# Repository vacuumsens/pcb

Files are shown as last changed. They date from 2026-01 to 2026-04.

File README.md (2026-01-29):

# PCB Schematic Projects

KiCad PCB design projects for VacuumSens.

## Project Structure

```
SchematicProjects/
├── libs/                    # Centralized component libraries
│   ├── easyeda2kicad.kicad_sym
│   ├── easyeda2kicad.pretty/
│   └── easyeda2kicad.3dshapes/
├── charging-circuit/V1/     # Charging circuit project
├── RS232-converter/V1/      # RS232 converter project
└── ...
```

## Importing Components from EasyEDA/LCSC

There are two methods to import components:

---

### Method 1: Command Line (easyeda2kicad)

Best for batch imports or when you know the LCSC part number.

#### Prerequisites

Install the `easyeda2kicad` Python tool:

```bash
pip install easyeda2kicad
```

#### Import a Component

Use the alias (already configured in `.zshrc`):

```bash
easyeda2kicad-import <LCSC_ID>
```

**Example:**
```bash
easyeda2kicad-import C49018
```

This downloads the symbol, footprint, and 3D model to the centralized `libs/` folder.

#### Manual Import (without alias)

```bash
easyeda2kicad --full --overwrite --output /Users/andrewyanez/Documents/KiCad/7.0/symbols/SchematicProjects/libs --lcsc_id C49018
```

---

### Method 2: KiCad Plugin (EasyEDA/LCSC Plugin)

Best for browsing and importing directly within KiCad.

#### Installation

1. In KiCad, go to **Plugin and Content Manager**
2. Search for "EasyEDA" or "LCSC"
3. Install the plugin

#### Usage

1. Open your KiCad project
2. Go to **Tools → EasyEDA Library** (or similar menu item)
3. Search for a component by name or LCSC part number
4. Click **Import** - the plugin will create:
   - `LCSC/EasyEDA.kicad_sym` (symbols)
   - `LCSC/EasyEDA.pretty/` (footprints)
   - `LCSC/EasyEDA.3dshapes/` (3D models)

**Note:** The plugin saves files locally in your project folder under `LCSC/`. This is project-specific, not centralized.

---

### After Importing (Both Methods)

1. Open your KiCad project
2. The library should be available in the schematic/PCB editor
3. Add the new symbol/footprint to your design
4. Commit changes to git:
   ```bash
   git add -A && git commit -m "Add component CXXXXX"
   git push
   ```

---

### Which Method to Use?

| Method | Pros | Cons |
|---|---|---|
| **easyeda2kicad** (CLI) | Centralized in `libs/`, shared across projects | Requires terminal |
| **KiCad Plugin** | Visual browsing, integrated in KiCad | Project-local, can create duplicates |

**Recommendation:** Use the CLI for components you'll reuse. Use the plugin for quick project-specific imports.

## Library Configuration

Projects reference the centralized library using relative paths:

**sym-lib-table:**
```
(lib (name "easyeda2kicad")(type "KiCad")(uri "${KIPRJMOD}/../../libs/easyeda2kicad.kicad_sym"))
```

**fp-lib-table:**
```
(lib (name "easyeda2kicad")(type "KiCad")(uri "${KIPRJMOD}/../../libs/easyeda2kicad.pretty"))
```

## Finding LCSC Part Numbers

1. Go to [LCSC.com](https://www.lcsc.com) or [JLCPCB Parts](https://jlcpcb.com/parts)
2. Search for your component
3. The LCSC part number starts with "C" (e.g., C49018)

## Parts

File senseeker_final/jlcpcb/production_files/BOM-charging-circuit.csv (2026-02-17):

Comment | Designator | Footprint | LCSC | Quantity
0.1uF | C7 | C0402 | C1525 | 1
10k | R8,RPROG3 | R0805 | C17414 | 2
12V_Sensor | H1 | HDR-TH_2P-P2.54-V-M-1 | C124375 | 1
1k | RPROG1 | R1206 | C4410 | 1
22k | R3 | R0805 | C17560 | 1
22uF | C3,C4,C5,C8 | C1206 | C1859 | 4
22uF | L1,L2 | IND-SMD_L7.5-W7.5 | C19268629 | 2
3k | R4 | R0603 | C177274 | 1
4.7k | R10 | R0805 | C17673 | 1
4.7uF | C2,C6 | C0805 | C1779 | 2
470 | R11,R6,R7 | R0805 | C17710 | 3
5.1k | R1,R2 | R0603 | C23186 | 2
91k | R9 | R0805 | C17866 | 1
Battery Input | U5 | CONN-TH_S2B-PH-K-S-GW | C157932 | 1
Blue | LED1 | LED0805-R-RD | C2293 | 1
Green | LED3 | LED0805-R-RD | C2292 | 1
MCP73871 | U4 | QFN-20_L4.0-W4.0-P0.5-BL-EP | C511310 | 1
RaspberryPI | H2 | HDR-TH_2P-P2.54-V-M-1 | C124375 | 1
Red | LED2 | LED1206-R-RD_RED | C49018 | 1
Schottky | D4,D6 | SMA_L4.3-W2.6-LS5.2-RD | C8678 | 2
USB_C_Receptacle_PowerOnly_6P | J1 | TYPE-C-SMD_TYPE-C-6P | C283540 | 1
MT3608 | U2 | SOT-23-6_L2.9-W1.6-P0.95-LS2.8-BL |  | 1
MT3608 | U3 | SOT-23-6_L2.9-W1.6-P0.95-LS2.8-BL |  | 1
USB_A | J2 | USB-A-TH_AF-WJDG |  | 1

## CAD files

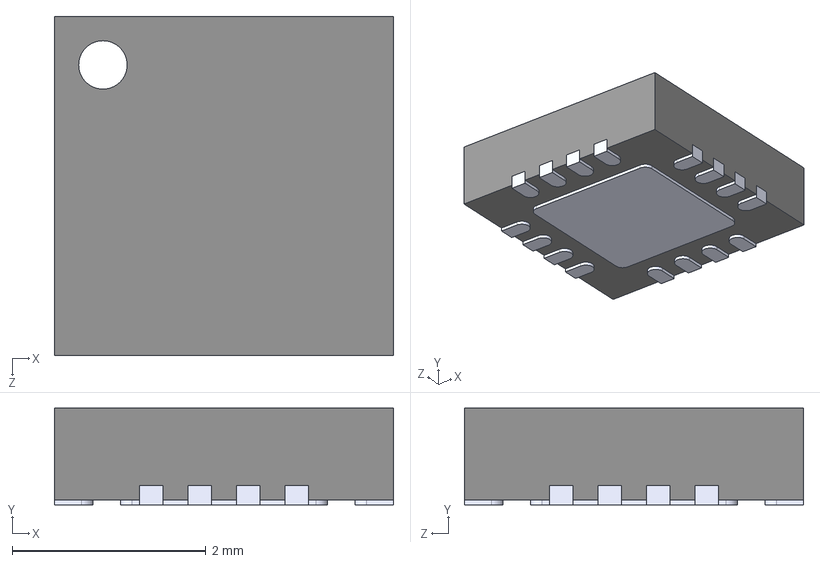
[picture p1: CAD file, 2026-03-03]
3S-Battery/BQ24650RVAR/BQ24650RVAR.step
3.50 x 1.00 x 3.50 mm

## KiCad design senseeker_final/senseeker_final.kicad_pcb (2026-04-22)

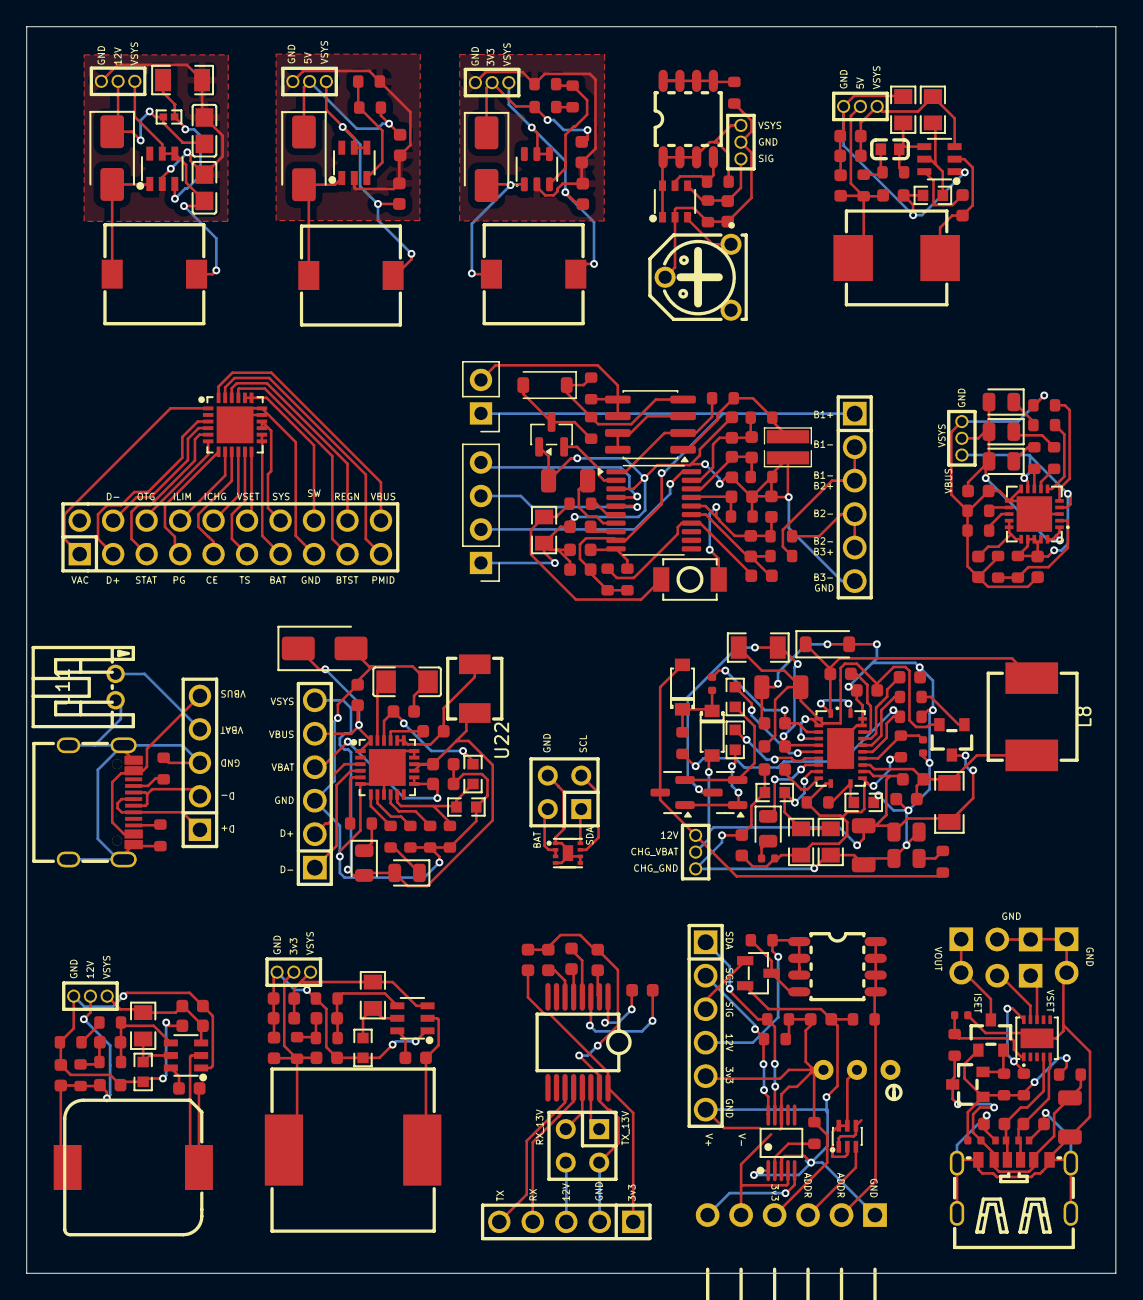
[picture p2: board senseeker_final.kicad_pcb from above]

Board: 2 copper layers, 82.6 x 94.6 mm, 232 parts (0 on the bottom side), 196 nets.

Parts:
C1, C2: 22uf; C0805
C3, C5, C6, C12, C17, C18, C19, C20, C21, C32, C33, C34, C38, C44, C45, C54, C57, C61: 100nF; C_0603
C4, C7, C10, C11, C35, C36, C40, C41, C46, C47: 22uF; C_0603
C8, C14, C22, C29, C37, C43, C50: 10uF; C_0603
C9, C31, C42, C53, C55, C70, C71: 1uF; C_0603
C13: 22uf; C1206
C15, C23, C51, C52: 4.7uF; C_0603
C16, C56: 47nF; C_0603
C24, C25: 330pF; C_0603
C26, C28: 1uF; C_0402
C27, C58, C72: 10uF; C_1206
C30: 1uF; C_1206
C39: 47pF; C_0603
C48: 75pf; C0603
C49: 100pF; C_0603
C59: 22uF; C_0805
C_sense1, C_sense2, C_sense3: 100nF; C_0603
Cc0, Cc1: 1uF; C_0603
Cin1: 2.2uF; C_0805
D1: 1N4148W; D_SOD-123
D2, D11: H5VU10U; D_DFN1006-2L
D3, D9, D13: Green; D_0805
D4, D5, D6: SS34; D_SMA
D7, D8: Red; D_0805
D10: Yellow; D_0805
D12, D100: MBR0530; SOD-123_L2.8-W1.8-LS3.7-RD
D14: SS14; D_SMA
D19: B0530W; D_SOD-123
H2, H11: 77311-462K05LF; HDR-TH_5P-P2.54-V-M
H3, H4, H9: Header-Male-2.54_1x6; HDR-TH_6P-P2.54-V-M-1
H5, H6, H7, H8: 68000-102HLF; HDR-TH_2P-P2.54-V-M-1
J1: 2.54-1*6PHeader-RA; HDR-TH_6P-P2.54-H-M-W10.0
J2: USB_C_Receptacle_PowerOnly_6P; TYPE-C-SMD_TYPE-C-6P
J10: Conn_01x02; PinHeader_1x02_P2.54mm_Vertical
J11: Conn_01x04; PinHeader_1x04_P2.54mm_Vertical
L1, L2, L3: 22uH; IND-SMD_L7.5-W7.5
L5: 10uh; IND-SMD_L7.5-W6.6
L6: 6.8uh; IND-SMD_L12.3-W12.3_SMDRI127
L7: 15uh; IND-SMD_L10.4-W10.3
L8: 2.2uH; IND-SMD_L6.7-W6.6
P1, P2: Header-Male-2.54_2x2; HDR-TH_4P-P2.54-V-M-R2-C2-S2.54-1
P3, P4, P5, P6, P7, P8, P9, P10, P11: 1.27mm/1*3p; HDR-TH_3P-P1.27-V-M-1
Q1: 2N7002; SOT-23-3_L2.9-W1.3-P1.90-LS2.4-BR
Q2, Q8: CJQ4435; SOP-8_L5.0-W4.0-P1.27-LS6.2-BL
Q3: currentmirror; SOT-363-6_L2.2-W1.3-P0.65-LS2.1-BL
Q4: BSS84; SOT-23
Q5: AO4892; SOIC-8_3.9x4.9mm_P1.27mm
Q6, Q7, Q11: AO3401A; SOT-23_L2.9-W1.3-P1.90-LS2.4-BR
Q9, Q10: AO3400A; Q_SOT-23
R1: 11.3kohm; R1206
R2: 215kohm; R0402
R3, R46: 3kΩ; R_0603
R4: 10Ω; R_0402
R5: 5.23k; R0805
R6, R38, R45, R50, R61, R76: 100kΩ; R_0603
R7: 32.4k; R0603
R8, R9, R14, R16, R29, R39: 10kΩ; R_0603
R10, R52: 22kΩ; R_0603
R11, R15, R26, R60: 1MΩ; R_0603
R12, R13, R21, R30, R31, R35: 5.1kΩ; R_0603
R17, R20, R24, R53: 2.2kΩ; R_0603
R18: 6.8kΩ; R_0603
R19: 2kΩ; R_0603
R22: 240Ω; R_0603
R25: 150Ω; R_0603
R27: 5.23kohm; R0603
R28: 30.1kohm; R0603
R32: 100Ω; R_0603
R33: 10Ω; R_0603
R34: 330kΩ; R_0603
R36: 12kΩ; R_0603
R37, R44, R49, R77: 49.9kΩ; R_0603
R40, R42, R47: 511k; R0805
R41, R43, R48: 105k; R0603
R51: 13.3k; R0805
R54: RM065-204(200K); RES-ADJ-TH_3P-L7.3-W6.4-P5.00-R
R55: 3296W-1-504LF; RES-ADJ-TH_3296W
R56, R57, R58: 470Ω; R_0603
R59: 110kΩ; R_0603
R62: 30.1k; R0603
R63, R75: 4.02k; R0603
R64: 1.5kΩ; R_0402
R65: 1kΩ; R_0603
R66: 33kΩ; R_0402
RPROG1, RPROG2, RPROG5: 1kΩ; R_0603
RPROG3: 10kΩ; R_0603
R_AC1, R_AC2: 10m; R1206
R_sense1, R_sense2: 100Ω; R_0603
Rc0, Rc1, Rc2, Rc3: 100Ω; R_0603
Rin1: 2Ω; R_0603
Rsense1: LTR18EZPFSR015; R0612
SW1: TS-1088R-02026; SW-SMD_L3.9-W3.0-P4.45
U1: MAX17048G+T10; TDFN-8_L2.0-W2.0-P0.50-BL-EP1.2
U2, U3, U6: MT3608; SOT-23-6_L2.9-W1.6-P0.95-LS2.8-BL
U4: TPL5110DDCT; TSOT-23-6_L2.9-W1.6-P0.95-LS2.8-BR
U5, U10: BQ25606RGER; VQFN-24_L4.0-W4.0-P0.50-TL-EP2.8
U7: Z-21320110021001; HDR-TH_20P-P2.54-V-M-R2-C10-S2.54
U8: MAX3232CDBR; SSOP-16_L6.2-W5.3-P0.65-LS7.8-BL
U9: ADS1115IDGSR; MSOP-10_L3.0-W3.0-P0.50-LS5.0-BL
U11: Battery Input; CONN-TH_S2B-PH-K-S-GW
U12: BQ24170RGYR; VQFN-24_L5.5-W3.5-P0.50-BL-EP-2
U13, U19, U20: TPS54302DDCR_C311983; SOT-23-6_L2.9-W1.6-P0.95-LS2.8-BL
U14, U16: NTC10K/0805/F; R0805
U15: BQ76920PW; TSSOP-20_4.4x6.5mm_P0.65mm
U17: HUSB238_002DD; DFN-10_L3.0-W3.0-P0.50-BL-EP2.5
U21: MCP73871; QFN-20_L4.0-W4.0-P0.5-BL-EP
U22: SRP4020TA-1R0M; IND-SMD_L4.5-W4.1_SRP4020TA
USBC1: TYPE-C-31-M-12; USB-C_SMD-TYPE-C-31-M-12_1

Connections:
1D+: H3.2, U10.3 (D+)
1D-: H3.1, U10.4 (D-)
2D+: U5.3 (D+), U7.3
2D-: U5.4 (D-), U7.4
3V3BGND: C29.2, C32.2, C40.2, C41.2, P4.3, R43.1, R52.2, U13.1 (GND)
3V3BOOT: C33.2, L6.1, U13.2 (SW)
3V3BVOUT: C40.1, C41.1, L6.2, P4.2, R44.1
3V3BVSYS: C29.1, C32.1, P4.1, R42.2, U13.3 (VIN)
3V3FB: C39.2, R45.2, R52.1, U13.4 (FB)
3V3GND: C10.2, C11.1, P7.3, R19.2, U6.2 (GND)
3V3VOUT: C11.2, D6.1, P7.2, R18.1
3V3VSYS: C10.1, L3.1, P7.1, U6.4 (EN), U6.5 (IN)
5BGND: C43.2, C44.2, C46.2, C47.2, P9.3, R48.1, R51.2, U20.1 (GND)
5BOOT: C45.2, L5.1, U20.2 (SW)
5BVOUT: C46.1, C47.1, L5.2, P9.2, R49.1
5BVSYS: C43.1, C44.1, P9.1, R47.2, U20.3 (VIN)
5FB: C48.1, R50.2, R51.1, U20.4 (FB)
5GND: C4.1, C7.2, P6.3, R3.2, U2.2 (GND)
5VOUT: C4.2, D5.1, P6.2, R10.1
5VSYS: C7.1, L1.1, P6.1, U2.4 (EN), U2.5 (IN)
12BGND: C35.2, C36.2, C37.2, C38.2, P8.3, R41.1, R46.1, U19.1 (GND)
12BOOT: C34.2, L7.1, U19.2 (SW)
12BVOUT: C35.1, C36.1, L7.2, P8.2, R37.1
12BVSYS: C37.1, C38.1, P8.1, R40.2, U19.3 (VIN)
12FB: C49.2, R38.2, R53.1, U19.4 (FB)
12GND: C1.1, C2.1, P5.3, R1.1, U3.2 (GND)
12VOUT: C1.2, D4.1, P5.2, R2.1
12VSYS: C2.2, L2.1, P5.1, U3.4 (EN), U3.5 (IN)
12V_Adapter: D12.2 (A), P11.1, Q9.3 (D), Rin1.1
A0: J1.5, U9.4 (AIN0)
A1: J1.6, U9.5 (AIN1)
ALERT-2-RASPI: J11.2, U15.20 (ALERT)
BAT2: U5.13 (BAT), U5.14 (BAT), U7.13
BAT_1 (+): C31.2, H9.1, J10.1, R32.1, Rc3.2, U15.9 (REGSRC)
BAT_1 (-): H9.2, H9.3, Rc2.2
BAT_2 (-): H9.4, H9.5, Rc1.2
BAT_3 (-): C8.1, C23.2, C30.1, C31.1, C_sense1.1, C_sense3.2, Cc0.2, Cc1.2, H9.6, J11.1, Q4.1 (G), R_sense2.2, Rc0.2, Rsense1.2, U14.2, U15.3 (VSS)
BTST: U5.21 (BTST), U7.17
CC1: C25.1, D2.1, J2.A5 (CC1), U17.4 (CC1)
CC2: C24.1, D11.1, J2.B5 (CC2), U17.5 (CC2)
CE2: U5.9 (~CE), U7.9
CHG_GND: C6.2, C42.2, C53.2, C55.2, C57.2, C58.2, C59.2, C61.1, C72.2, Cin1.2, D19.2, P11.3, R7.1, R61.2, R62.2, R66.2, U12.22 (PGND), U12.23 (PGND), U12.25 (EP), U16.2
CHG_VBAT: C54.1, C58.1, C59.1, D100.2 (A), P11.2, Q11.3 (D), R_AC1.2, U12.15 (SRN)
D+: H2.1, USBC1.A6 (DP1), USBC1.B6 (DP2)
D-: H2.2, USBC1.A7 (DN1), USBC1.B7 (DN2)
DSUB3.3V: C21.1, H11.1, U8.16 (VCC)
DSUB12V: H11.3, P1.4
DSUBGND: C17.2, C18.2, C21.2, H11.2, P1.2, U8.15 (GND)
FUELBAT: P2.2, U1.2 (CELL), U1.3 (VDD)
FUELGND: P2.4, U1.1 (CTG), U1.4 (GND), U1.5 (~ALRT), U1.6 (QSTRT), U1.9 (EP)
FUELSCL: P2.3, U1.7 (SCL)
FUELSDA: P2.1, U1.8 (SDA)
GND1: C9.1, C13.2, C14.1, C15.2, C22.1, D14.2, H3.3, R22.1, R25.1, R28.2, R29.2, U10.6 (OTG), U10.9 (~CE), U10.17 (GND), U10.18 (GND), U10.25 (EP)
GND2: U5.17 (GND), U5.18 (GND), U5.25 (EP), U7.15
ICHG2: U5.10 (ICHG), U7.10
ILIM2: U5.8 (ILIM), U7.8
ISET: H5.2, U17.9 (ISET)
unnamed: C16.2, U10.19 (SW), U10.20 (SW), U22.1
unnamed: C39.1, R44.2, R45.1
unnamed: C48.2, R49.2, R50.1
unnamed: C49.1, R37.2, R38.1
unnamed: C56.1, D19.1, L8.1, U12.1 (SW), U12.24 (SW)
unnamed: Cin1.1, Rin1.2
unnamed: D1.2 (A), Q4.3 (D), R15.1
unnamed: D1.1 (K), Q5.4 (G2), R15.2, R26.1
unnamed: D3.1, R58.1
unnamed: D7.1, R57.1
unnamed: D8.1, R17.1
unnamed: D9.1, R24.1
unnamed: D10.1, R56.1
unnamed: D13.2, R64.2
unnamed: D12.1 (C), D100.1 (C), R4.1, R60.1
unnamed: J1.2, Q2.5 (D), Q2.6 (D), Q2.7 (D), Q2.8 (D), RPROG5.1
unnamed: J1.3, Q3.3 (C)
unnamed: Q1.3 (D), Q2.4 (G), R14.1
unnamed: Q4.2 (S), U15.2 (CHG)
unnamed: Q5.2 (G1), R11.1, U15.1 (DSG)
unnamed: Q5.3 (S2), Q5.7 (D1), Q5.8 (D1)
unnamed: C26.1, Q6.1 (G), Q7.1 (G), R35.2, R36.2, R77.2
unnamed: Q6.2 (S), Q7.2 (S), R77.1
unnamed: C26.2, C27.1, J2.A9 (VBUS), J2.B9 (VBUS), Q7.3 (D), R33.1, R36.1
unnamed: Q8.5 (D), Q8.6 (D), Q8.7 (D), Q8.8 (D), RPROG1.1
unnamed: Q8.4 (G), R9.1, U4.5 (DRV)
unnamed: C5.1, Q10.3 (D), R_AC2.1, U12.6 (ACP)
unnamed: Q9.1 (G), Q10.1 (G), R63.1
unnamed: Q9.2 (S), Q10.2 (S), R75.1
unnamed: Q11.1 (G), R65.2
unnamed: C5.2, C6.1, C72.1, Q11.2 (S), R_AC2.2, U12.2 (PVCC), U12.3 (PVCC), U12.5 (ACN)
unnamed: R16.1, SW1.2, U14.1
unnamed: R18.2, R20.1
unnamed: R46.2, R53.2
unnamed: R3.1, R10.2, U2.3 (FB)
unnamed: D5.2, L1.2, U2.1 (SW)
unnamed: R1.2, R2.2, U3.3 (FB)
unnamed: D4.2, L2.2, U3.1 (SW)
unnamed: R54.1, U4.3 (DELAY/M_DRV)
unnamed: R19.1, R20.2, U6.3 (FB)
unnamed: D6.2, L3.2, U6.1 (SW)
unnamed: C20.1, U8.1 (C1+)
unnamed: C20.2, U8.3 (C1-)
unnamed: C19.1, U8.4 (C2+)
unnamed: C19.2, U8.5 (C2-)
unnamed: C18.1, U8.2 (V+)
unnamed: C17.1, U8.6 (V-)
unnamed: R13.2, U9.2 (ALERT/RDY)
unnamed: C16.1, U10.21 (BTST)
unnamed: R22.2, U10.10 (ICHG)
unnamed: R25.2, U10.8 (ILIM)
unnamed: C13.1, U10.23 (PMID)
unnamed: R17.2, U10.5 (STAT)
unnamed: R27.2, R28.1, R29.1, U10.11 (TS)
unnamed: R24.2, U10.7 (~PG)
unnamed: R63.2, U12.8 (ACDRV)
unnamed: R6.2, R66.1, U12.17 (ACSET)
unnamed: C53.1, R4.2, U12.4 (AVCC)
unnamed: C56.2, U12.21 (BTST)
unnamed: R75.2, U12.7 (CMSRC)
unnamed: R7.2, R76.2, U12.13 (ISET)
unnamed: R60.2, R61.1, U12.18 (OVPSET)
unnamed: C55.1, U12.20 (REGN)
unnamed: C54.2, C57.1, L8.2, R_AC1.1, U12.16 (SRP)
unnamed: D13.1, U12.9 (STAT)
unnamed: R5.2, R62.1, U12.10 (TS), U16.1
unnamed: C61.2, U12.11 (TTC)
unnamed: R65.1, U12.19 (~BATDRV)
unnamed: C33.1, U13.6 (BOOT)
unnamed: R42.1, R43.2, U13.5 (EN)
unnamed: C8.2, R32.2, U15.10 (BAT)
unnamed: C30.2, U15.7 (CAP1)
unnamed: C_sense1.2, C_sense2.1, R_sense1.1, U15.19 (SRN)
unnamed: C_sense2.2, C_sense3.1, R_sense2.1, U15.18 (SRP)
unnamed: R16.2, U15.6 (TS1)
unnamed: Cc0.1, Rc0.1, U15.17 (VC0)
unnamed: C70.2, C71.1, Rc2.1, U15.15 (VC2)
unnamed: C70.1, Rc3.1, U15.14 (VC3)
unnamed: R35.1, U17.10 (GATE)
unnamed: C28.1, R33.2, U17.1 (VIN)
unnamed: C34.1, U19.6 (BOOT)
unnamed: R40.1, R41.2, U19.5 (EN)
unnamed: C45.1, U20.6 (BOOT)
unnamed: R47.1, R48.2, U20.5 (EN)
unnamed: RPROG2.2, U21.13 (PROG1)
unnamed: RPROG3.1, U21.12 (PROG3)
unnamed: R57.2, U21.8 (STAT1/~LBO)
unnamed: R58.2, U21.7 (STAT2)
unnamed: R39.1, U21.5 (THERM)
unnamed: R34.2, R59.1, U21.2 (VPCC)
unnamed: R56.2, U21.6 (~PG)
unnamed: R31.1, USBC1.A5 (CC1)
unnamed: R30.1, USBC1.B5 (CC2)
OTG2: U5.6 (OTG), U7.6
PACK-: J10.2, Q5.5 (D2), Q5.6 (D2), R26.2
PDGND: C24.2, C25.2, C27.2, C28.2, D2.2, D11.2, H6.1, H6.2, H7.1, H7.2, J2.A12 (GND), J2.B12 (GND), J2.S1 (SHIELD), U17.11 (GND)
PDVOUT: H8.1, H8.2, Q6.3 (D)
PG2: U5.7 (~PG), U7.7
PMID2: U5.23 (PMID), U7.19
PROTECT-: Q5.1 (S1), R11.2, R_sense1.2, Rsense1.1
PWMSIG: H4.3, Q1.1 (G)
REGN1: C15.1, R27.1, U10.22 (REGN)
REGN2: U5.22 (REGN), U7.18
RX: H11.4, U8.12 (ROUT1)
SCL-2-RASPI: J11.3, U15.5 (SCL)
SDA-2-RASPI: J11.4, U15.4 (SDA)
SLEEPGND: C3.2, P3.2, R8.2, R54.2, RPROG1.2, U4.2 (GND)
SLEEPSIG: C3.1, P3.3, R8.1, U4.4 (DONE)
SLEEPVSYS: P3.1, Q8.1 (S), Q8.2 (S), Q8.3 (S), R9.2, U4.1 (VDD), U4.6 (EN/ONE_SHOT)
STAT2: U5.5 (STAT), U7.5
SW2: U5.19 (SW), U5.20 (SW), U7.16
SYS2: U5.15 (SYS), U5.16 (SYS), U7.14
TEMP12V: H4.4, Q2.1 (S), Q2.2 (S), Q2.3 (S), R14.2
TEMPGND: C12.2, H4.6, J1.1, Q1.2 (S), Q3.1 (E), Q3.4 (E), RPROG5.2, U9.1 (ADDR), U9.3 (GND)
TEMPSCL: H4.2, R12.2, U9.10 (SCL)
TEMPSDA: H4.1, R21.2, U9.9 (SDA)
TS2: U5.11 (TS), U7.11
TX: H11.5, U8.11 (DIN1)
Temp3.3V: C12.1, H4.5, J1.4, R12.1, R13.1, R21.1, R55.3, U9.8 (VDD)
UART_RX_13V: P1.3, U8.13 (RIN1)
UART_TX_13V: P1.1, U8.14 (DOUT1)
USBGND: H2.3, R30.2, R31.2, U11.2, USBC1.1 (EH), USBC1.2 (EH), USBC1.3 (EH), USBC1.4 (EH), USBC1.A1B12 (GND), USBC1.B1A12 (GND)
V1GND: C50.1, C51.1, C52.1, P10.3, R39.2, R59.2, RPROG2.1, RPROG3.2, U21.3 (SEL), U21.10 (V_{SS}), U21.11 (V_{SS}), U21.21 (V_{SS})
V1VBAT: C52.2, U21.14 (V_{BAT}), U21.15 (V_{BAT}), U21.16 (V_{BAT_SENSE})
V1VBUS: C50.2, P10.1, R34.1, U21.4 (PROG2), U21.9 (~TE), U21.17 (CE), U21.18 (IN), U21.19 (IN)
V1VSYS: C51.2, D3.2, D7.2, D10.2, P10.2, U21.1 (OUT), U21.20 (OUT)
VAC2: U5.1 (VAC), U7.1
VBAT: H2.4, U11.1
VBAT1: C14.2, H3.4, U10.13 (BAT), U10.14 (BAT)
VBUS: H2.5, USBC1.A4B9 (VBUS), USBC1.B4A9 (VBUS)
VBUS1: C9.2, D14.1, H3.5, U10.1 (VAC), U10.24 (VBUS)
VBUS2: U5.24 (VBUS), U7.20
VC1: C71.2, Cc1.1, Rc1.1, SW1.1, U15.16 (VC1)
VCC: C23.1, U15.8 (REGOUT)
VREF: C42.1, R5.1, R6.1, R64.1, R76.1, U12.12 (VREF), U12.14 (CELL/FB)
VSET: H5.1, U17.8 (VSET)
VSET2: U5.12 (VSET), U7.12
VSYS1: C22.2, D8.2, D9.2, H3.6, U10.15 (SYS), U10.16 (SYS), U22.2
base: Q3.2 (B), Q3.5 (B), Q3.6 (C), R55.2

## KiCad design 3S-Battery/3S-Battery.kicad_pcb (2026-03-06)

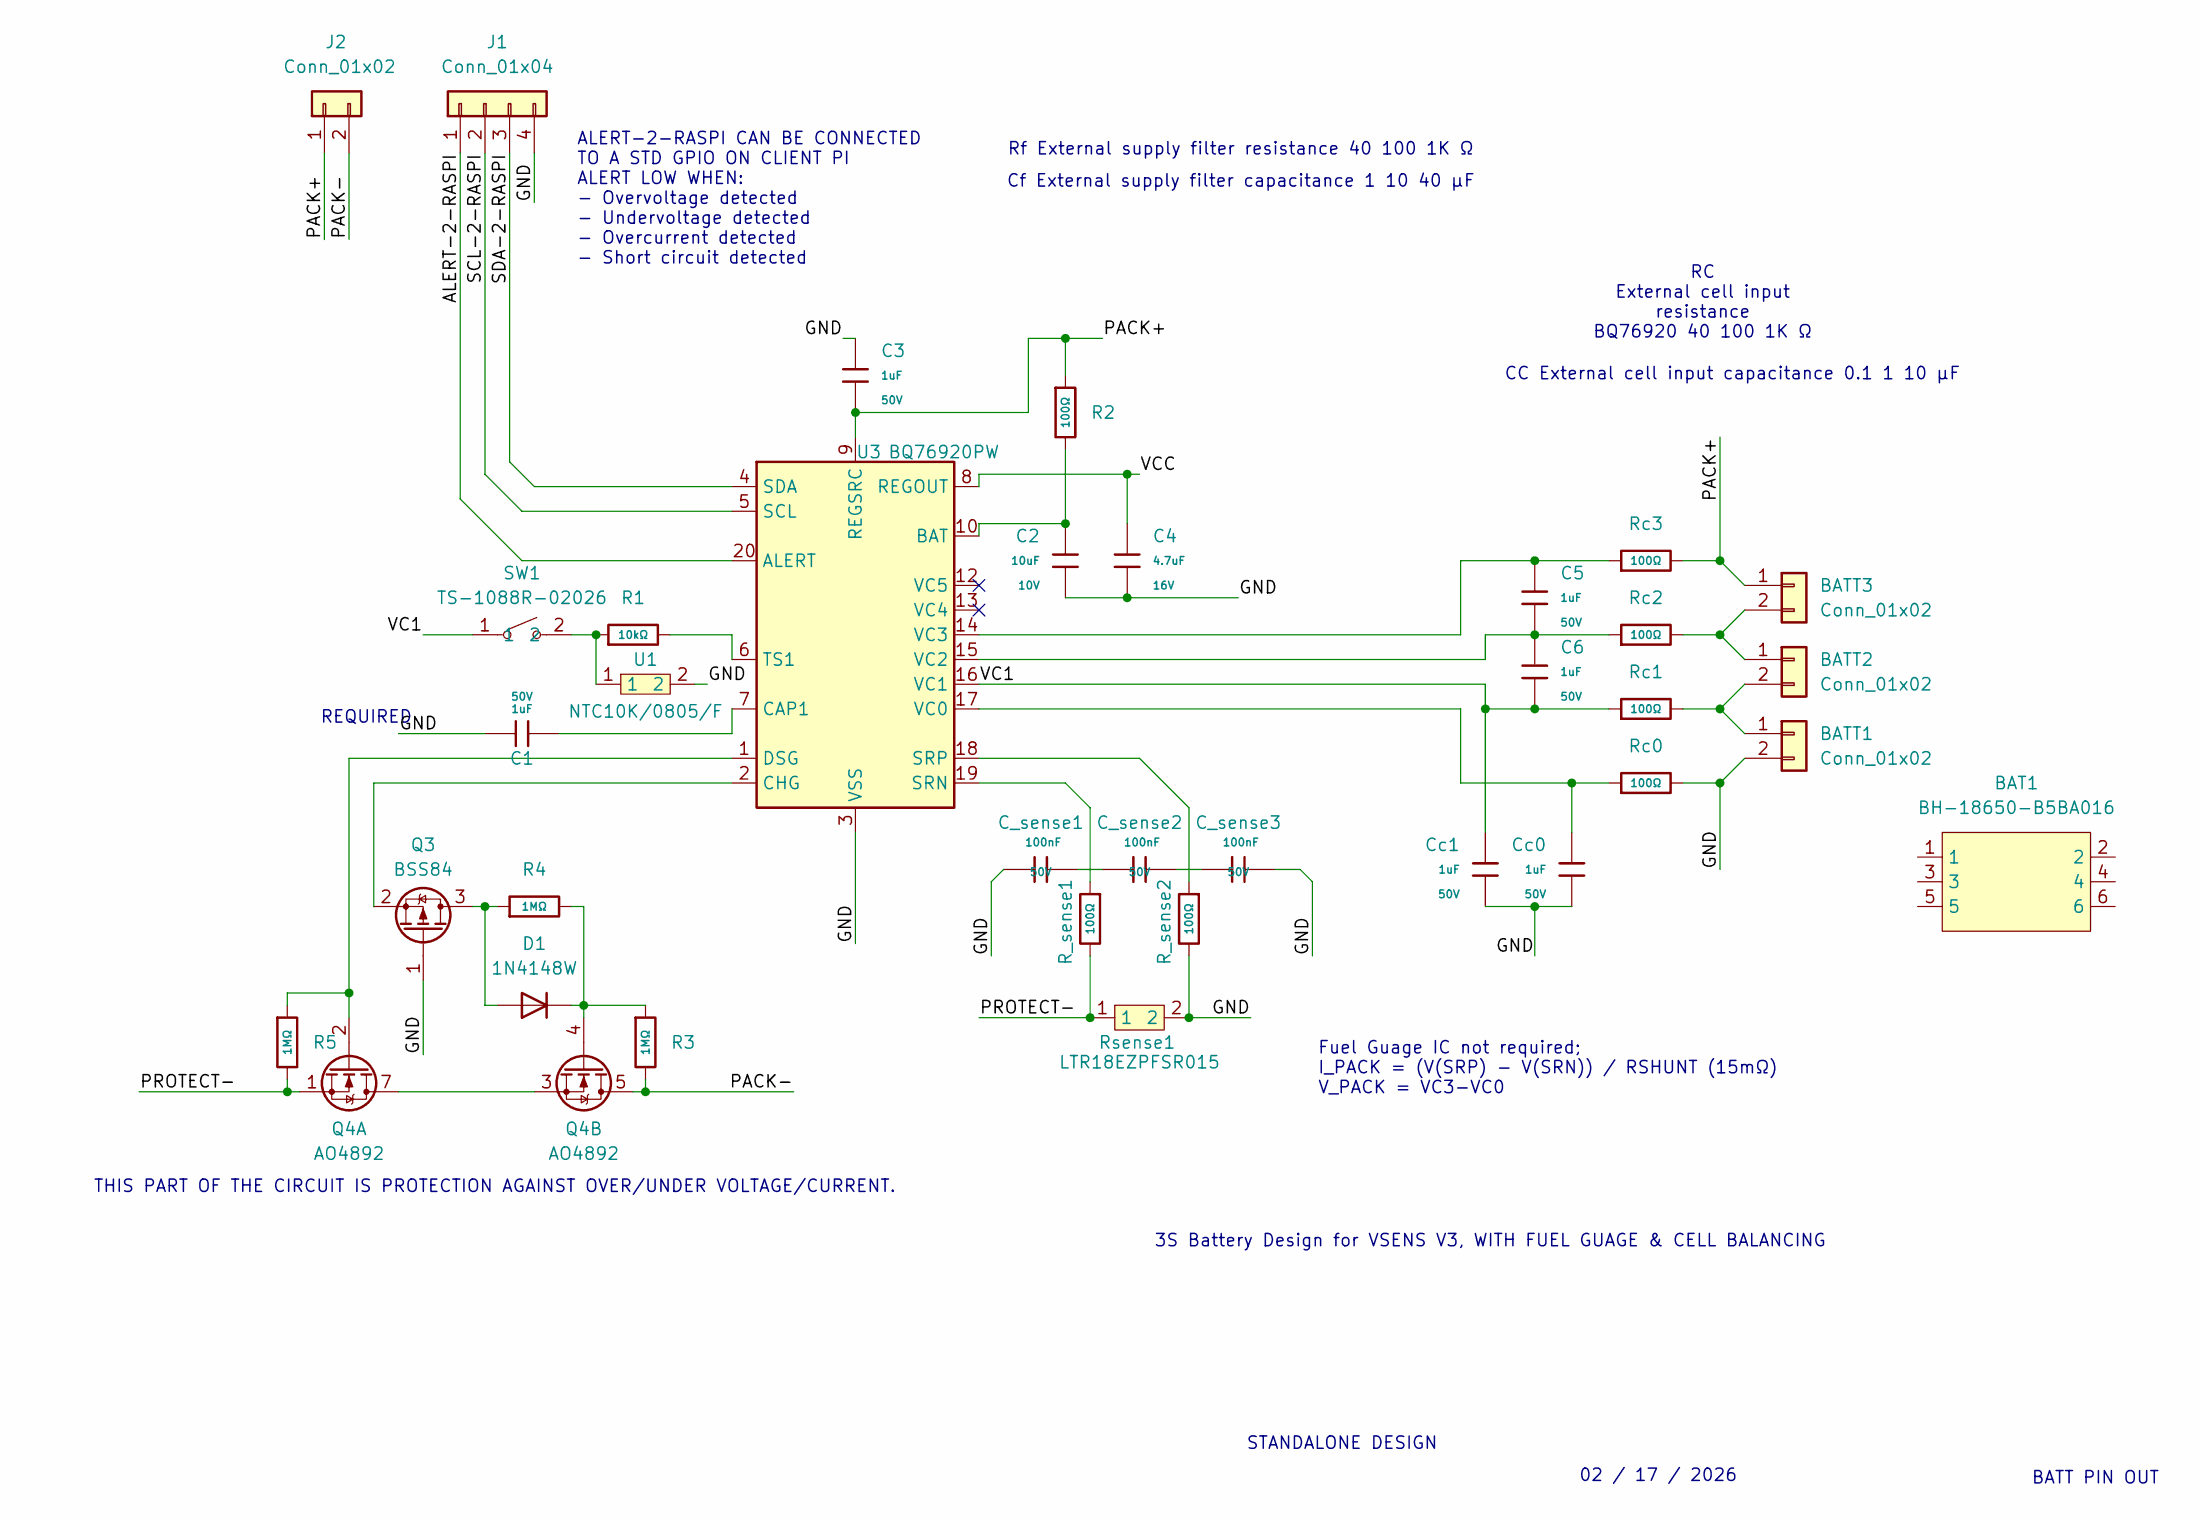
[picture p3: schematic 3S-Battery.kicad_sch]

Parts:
BAT1: BH-18650-B5BA016; BAT-SMD_BH-18650-B5BA016; LCSC Part C19184086
BATT1, BATT2, BATT3: Conn_01x02; PinHeader_1x02_P2.54mm_Vertical
C1: 1uF; C_1206; Voltage Rated 50V; Tolerance ±10%; Part CL31B105KBHNNNE; LCSC C1848
C2: 10uF; C_0603; Voltage Rated 10V; Tolerance ±10%; Part CL10A106KP8NNNC; LCSC C19702
C3, C5, C6: 1uF; C_0603; Voltage Rated 50V; Tolerance ±10%; Part CL10A105KB8NNNC; LCSC C15849
C4: 4.7uF; C_0603; Voltage Rated 16V; Tolerance ±10%; Part CL10A475KO8NNNC; LCSC C19666
C_sense1, C_sense2, C_sense3: 100nF; C_0603; Voltage Rated 50V; Tolerance ±10%; Part CC0603KRX7R9BB104; LCSC C14663
Cc0, Cc1: 1uF; C_0603; Voltage Rated 50V; Tolerance ±10%; Part CL10A105KB8NNNC; LCSC C15849
D1: 1N4148W; D_SOD-123
J1: Conn_01x04; PinHeader_1x04_P2.54mm_Vertical; LCSC Part C5116483
J2: Conn_01x02; PinHeader_1x02_P2.54mm_Vertical; LCSC Part C5360898
Q3: BSS84; SOT-23; LCSC Part C82079
Q4: AO4892; SOIC-8_3.9x4.9mm_P1.27mm; LCSC Part C357830
R1: 10kΩ; R_0603; Overload Voltage (Max) 75V; Tolerance ±1%; Part 0603WAF1002T5E; LCSC C25804
R2: 100Ω; R_0603; Overload Voltage (Max) 75V; Tolerance ±1%; Part 0603WAF1000T5E; LCSC C22775
R3, R4, R5: 1MΩ; R_0603; Overload Voltage (Max) 75V; Tolerance ±1%; Part 0603WAF1004T5E; LCSC C22935
R_sense1, R_sense2: 100Ω; R_0603; Overload Voltage (Max) 75V; Tolerance ±1%; Part 0603WAF1000T5E; LCSC C22775
Rc0, Rc1, Rc2, Rc3: 100Ω; R_0603; Overload Voltage (Max) 75V; Tolerance ±1%; Part 0603WAF1000T5E; LCSC C22775
Rsense1: LTR18EZPFSR015; R0612; LCSC Part C510175
SW1: TS-1088R-02026; SW-SMD_L3.9-W3.0-P4.45; LCSC Part C455280
U1: NTC10K/0805/F; R0805; LCSC Part C9900005726
U3: BQ76920PW; TSSOP-20_4.4x6.5mm_P0.65mm

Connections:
/ALERT-2-RASPI: J1.1, U3.20 (ALERT)
/GND: BATT1.2, C1.1, C2.1, C3.1, C4.2, C_sense1.1, C_sense3.2, Cc0.2, Cc1.2, J1.4, Q3.1 (G), R_sense2.2, Rc0.2, Rsense1.2, U1.2, U3.3 (VSS)
/PACK+: BATT3.1, C3.2, J2.1, R2.1, Rc3.2, U3.9 (REGSRC)
/PACK-: J2.2, Q4.5 (D2), Q4.6 (D2), R3.2
/PROTECT-: Q4.1 (S1), R5.2, R_sense1.2, Rsense1.1
/SCL-2-RASPI: J1.2, U3.5 (SCL)
/SDA-2-RASPI: J1.3, U3.4 (SDA)
/VC1: C6.2, Cc1.1, Rc1.1, SW1.1, U3.16 (VC1)
/VCC: C4.1, U3.8 (REGOUT)
unnamed: BATT1.1, BATT2.2, Rc1.2
unnamed: BATT2.1, BATT3.2, Rc2.2
unnamed: C_sense1.2, C_sense2.1
unnamed: C_sense2.2, C_sense3.1
unnamed: D1.2 (A), Q3.3 (D), R4.1
unnamed: D1.1 (K), Q4.4 (G2), R3.1, R4.2
unnamed: Q3.2 (S), U3.2 (CHG)
unnamed: Q4.2 (G1), R5.1, U3.1 (DSG)
unnamed: Q4.3 (S2), Q4.7 (D1), Q4.8 (D1)
unnamed: R1.1, SW1.2, U1.1
unnamed: C2.2, R2.2, U3.10 (BAT)
unnamed: C1.2, U3.7 (CAP1)
unnamed: R_sense1.1, U3.19 (SRN)
unnamed: R_sense2.1, U3.18 (SRP)
unnamed: R1.2, U3.6 (TS1)
unnamed: Cc0.1, Rc0.1, U3.17 (VC0)
unnamed: C5.2, C6.1, Rc2.1, U3.15 (VC2)
unnamed: C5.1, Rc3.1, U3.14 (VC3)

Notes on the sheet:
REQUIRED
02 / 17 / 2026
Fuel Guage IC not required; I_PACK = (V(SRP) - V(SRN)) / RSHUNT (15mΩ) V_PACK = VC3-VC0
STANDALONE DESIGN
RC External cell input resistance BQ76920 40 100 1K Ω
Rf External supply filter resistance 40 100 1K Ω
BATT PIN OUT
Cf External supply filter capacitance 1 10 40 µF
THIS PART OF THE CIRCUIT IS PROTECTION AGAINST OVER/UNDER VOLTAGE/CURRENT.
CC External cell input capacitance 0.1 1 10 µF
ALERT-2-RASPI CAN BE CONNECTED TO A STD GPIO ON CLIENT PI ALERT LOW WHEN: - Overvoltage detected - Undervoltage detected - Overcurrent detected - Short circuit detected
3S Battery Design for VSENS V3, WITH FUEL GUAGE & CELL BALANCING

Board: 2 copper layers, 35 parts (0 on the bottom side), 27 nets, no tracks yet.

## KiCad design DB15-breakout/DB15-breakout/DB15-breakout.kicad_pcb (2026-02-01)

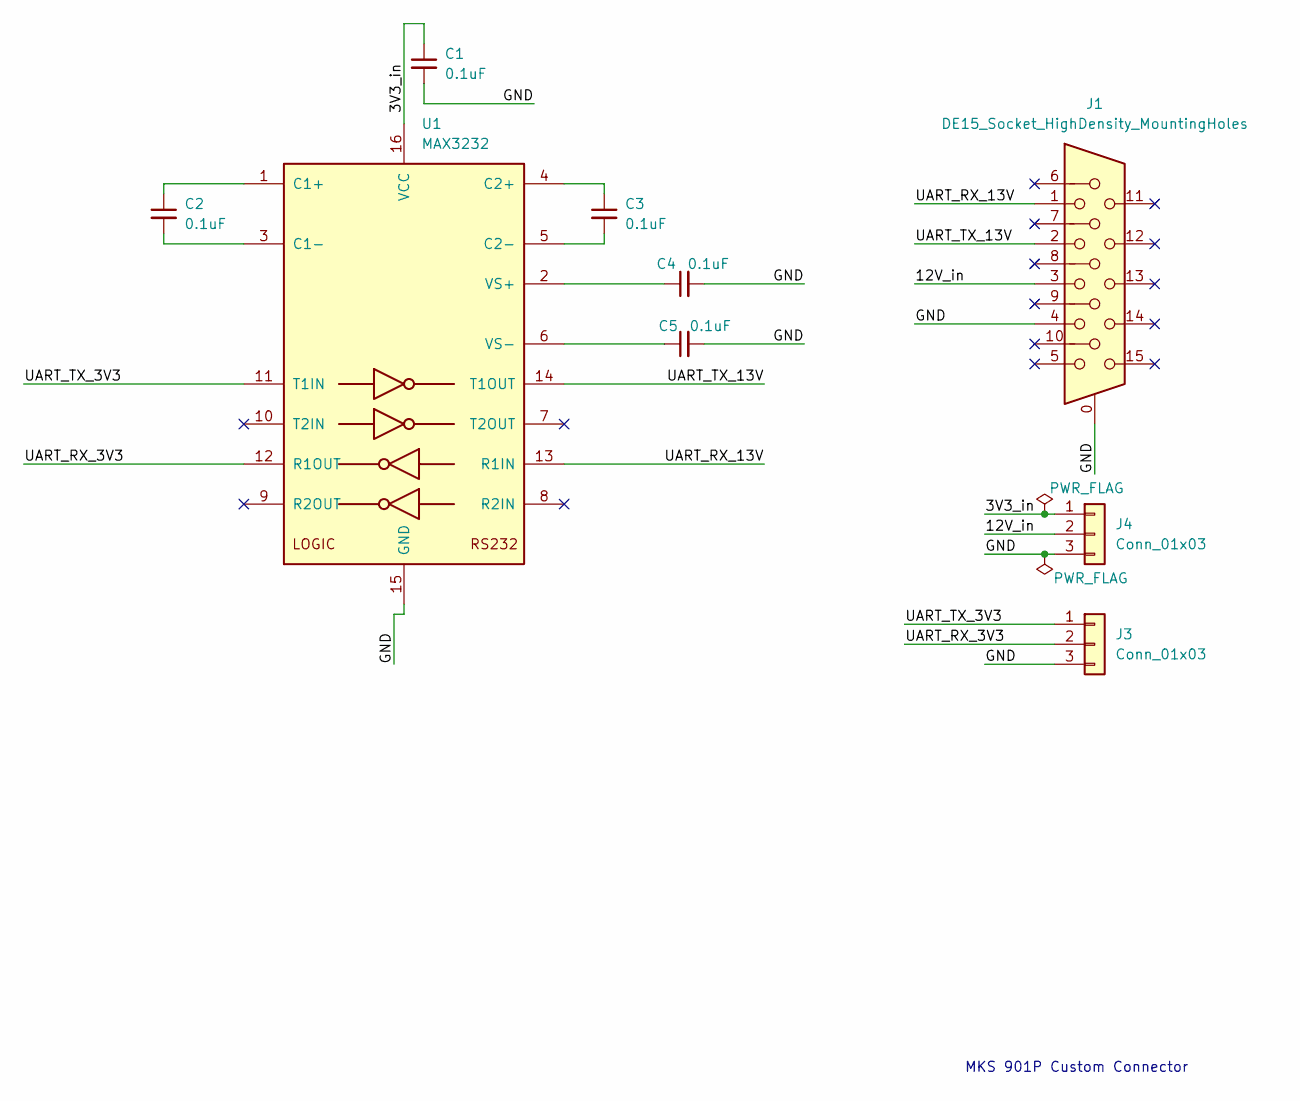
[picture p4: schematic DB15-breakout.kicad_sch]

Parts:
C1, C2, C3, C4, C5: 0.1uF; C_0603_1608Metric_Pad1.08x0.95mm_HandSolder
J1: DE15_Socket_HighDensity_MountingHoles; DSUB-15-HD_Socket_Horizontal_P2.29x1.90mm_EdgePinOffset3.03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
J3, J4: Conn_01x03; PinHeader_1x03_P2.54mm_Vertical
U1: MAX3232; SOIC-16_3.9x9.9mm_P1.27mm

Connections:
/3V3_in: C1.1, J4.1, U1.16 (VCC)
/12V_in: J1.3, J4.2
/GND: C1.2, C4.2, C5.2, J1.0, J1.4, J3.3, J4.3, U1.15 (GND)
/UART_RX_3V3: J3.2, U1.12 (R1OUT)
/UART_RX_13V: J1.1, U1.13 (R1IN)
/UART_TX_3V3: J3.1, U1.11 (T1IN)
/UART_TX_13V: J1.2, U1.14 (T1OUT)
unnamed: C2.1, U1.1 (C1+)
unnamed: C2.2, U1.3 (C1-)
unnamed: C3.1, U1.4 (C2+)
unnamed: C3.2, U1.5 (C2-)
unnamed: C4.1, U1.2 (VS+)
unnamed: C5.1, U1.6 (VS-)

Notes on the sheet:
MKS 901P Custom Connector

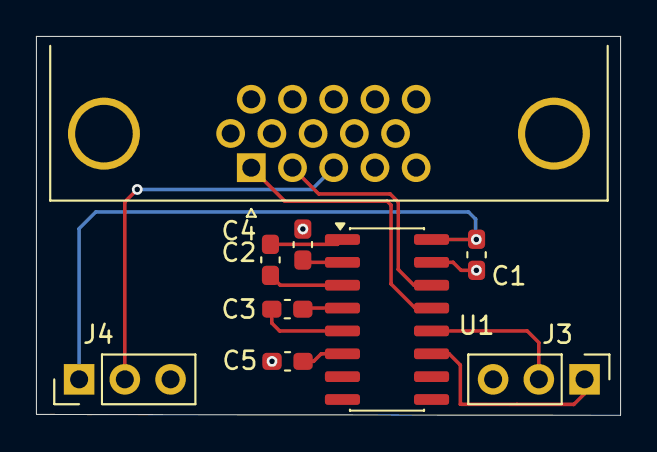
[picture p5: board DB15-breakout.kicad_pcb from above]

Board: 2 copper layers, 32.4 x 21.0 mm, 9 parts (0 on the bottom side), 13 nets.

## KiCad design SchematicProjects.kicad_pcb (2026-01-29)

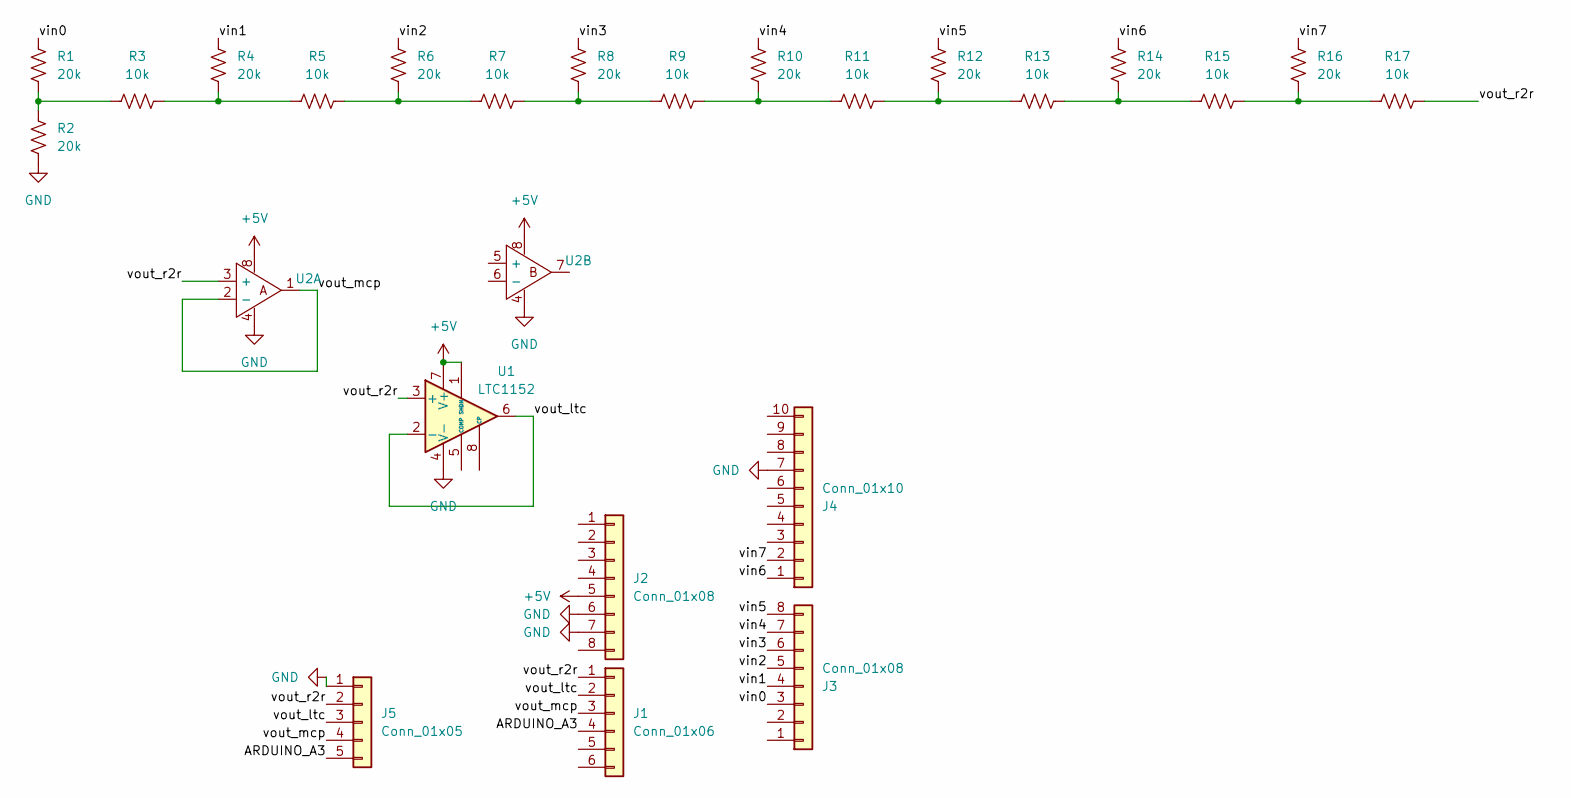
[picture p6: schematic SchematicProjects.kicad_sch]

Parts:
J1: Conn_01x06; PinHeader_1x06_P2.54mm_Vertical
J2, J3: Conn_01x08; PinHeader_1x08_P2.54mm_Vertical
J4: Conn_01x10; PinHeader_1x10_P2.54mm_Vertical
J5: Conn_01x05; PinHeader_1x05_P2.54mm_Vertical
R1, R2, R4, R6, R8, R10, R12, R14, R16: 20k; R_Axial_DIN0207_L6.3mm_D2.5mm_P10.16mm_Horizontal
R3, R5, R7, R9, R11, R13, R15, R17: 10k; R_Axial_DIN0207_L6.3mm_D2.5mm_P10.16mm_Horizontal
U1: LTC1152; SOIC-8_3.9x4.9mm_P1.27mm
U2: SOIC-8

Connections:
+5V: J2.5, U1.1 (SHDN), U1.7 (V+), U2.8
/ARDUINO_A3: J1.4, J5.5
/vin0: J3.3, R1.1
/vin1: J3.4, R4.1
/vin2: J3.5, R6.1
/vin3: J3.6, R8.1
/vin4: J3.7, R10.1
/vin5: J3.8, R12.1
/vin6: J4.1, R14.1
/vin7: J4.2, R16.1
/vout_ltc: J1.2, J5.3, U1.2 (-), U1.6
/vout_mcp: J1.3, J5.4, U2.1, U2.2 (-)
/vout_r2r: J1.1, J5.2, R17.2, U1.3 (+), U2.3 (+)
GND: J2.6, J2.7, J4.7, J5.1, R2.2, U1.4 (V-), U2.4
unnamed: R1.2, R2.1, R3.1
unnamed: R3.2, R4.2, R5.1
unnamed: R5.2, R6.2, R7.1
unnamed: R7.2, R8.2, R9.1
unnamed: R9.2, R10.2, R11.1
unnamed: R11.2, R12.2, R13.1
unnamed: R13.2, R14.2, R15.1
unnamed: R15.2, R16.2, R17.1

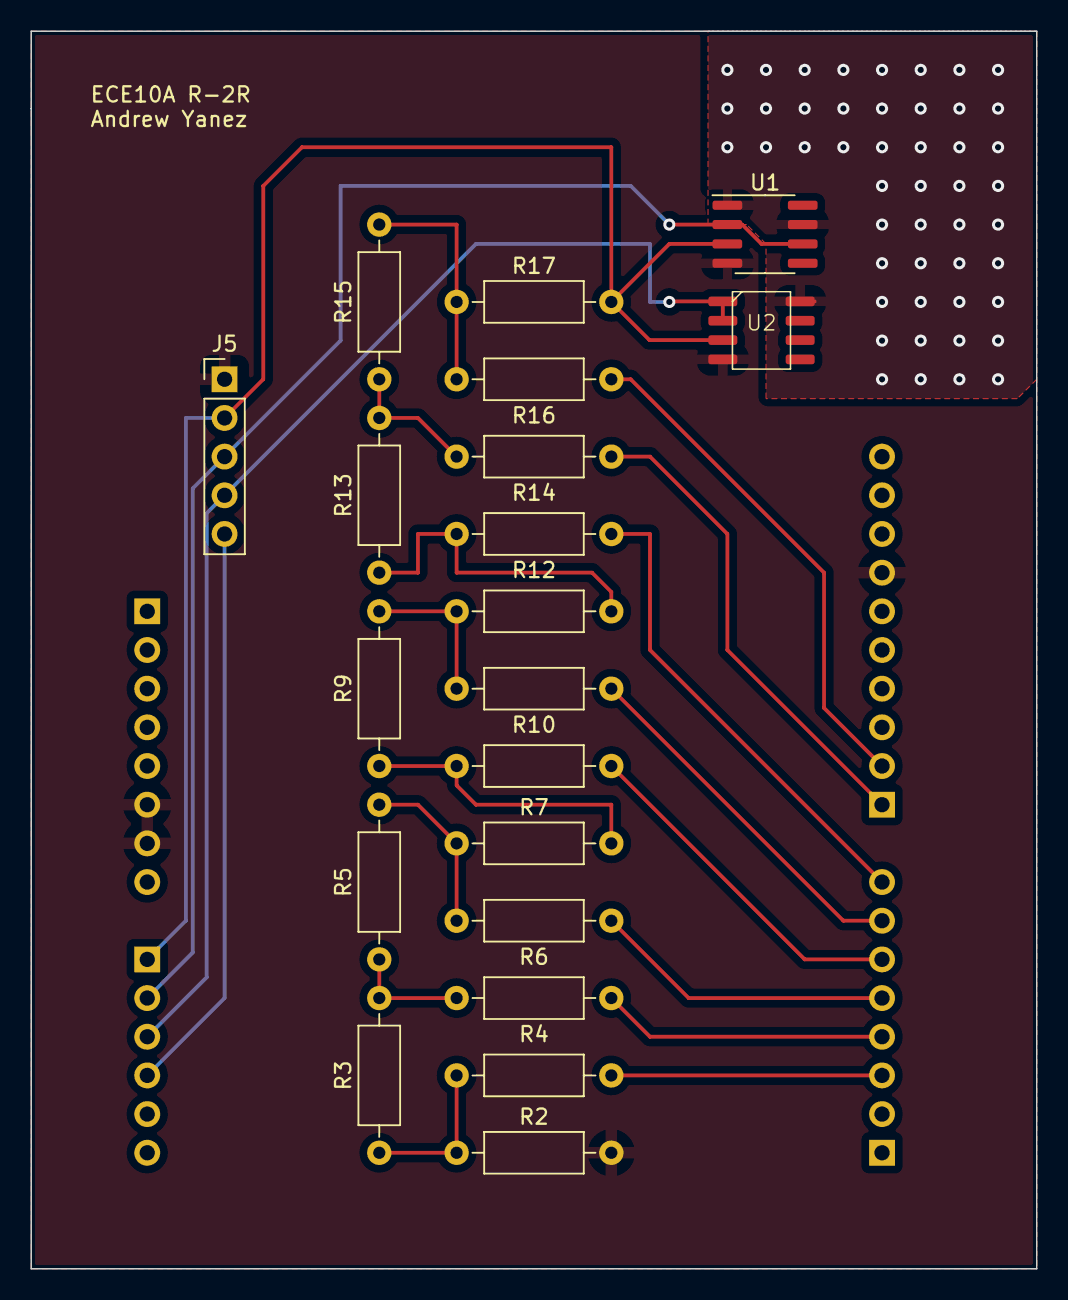
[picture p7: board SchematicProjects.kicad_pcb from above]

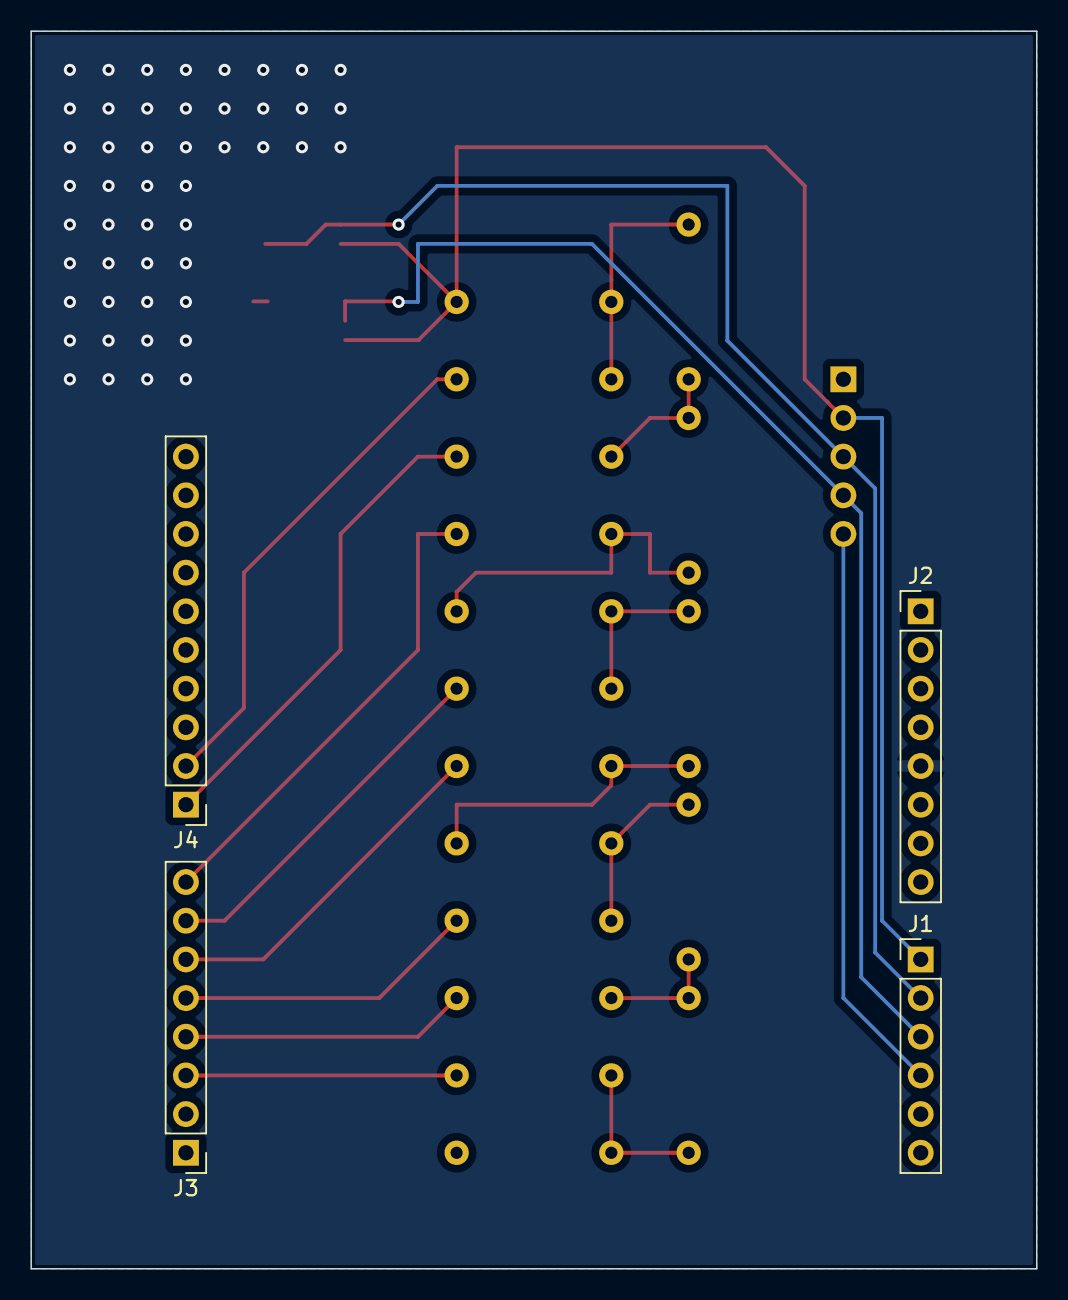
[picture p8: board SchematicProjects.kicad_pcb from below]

Board: 2 copper layers, 66.0 x 81.3 mm, 24 parts (4 on the bottom side), 22 nets.

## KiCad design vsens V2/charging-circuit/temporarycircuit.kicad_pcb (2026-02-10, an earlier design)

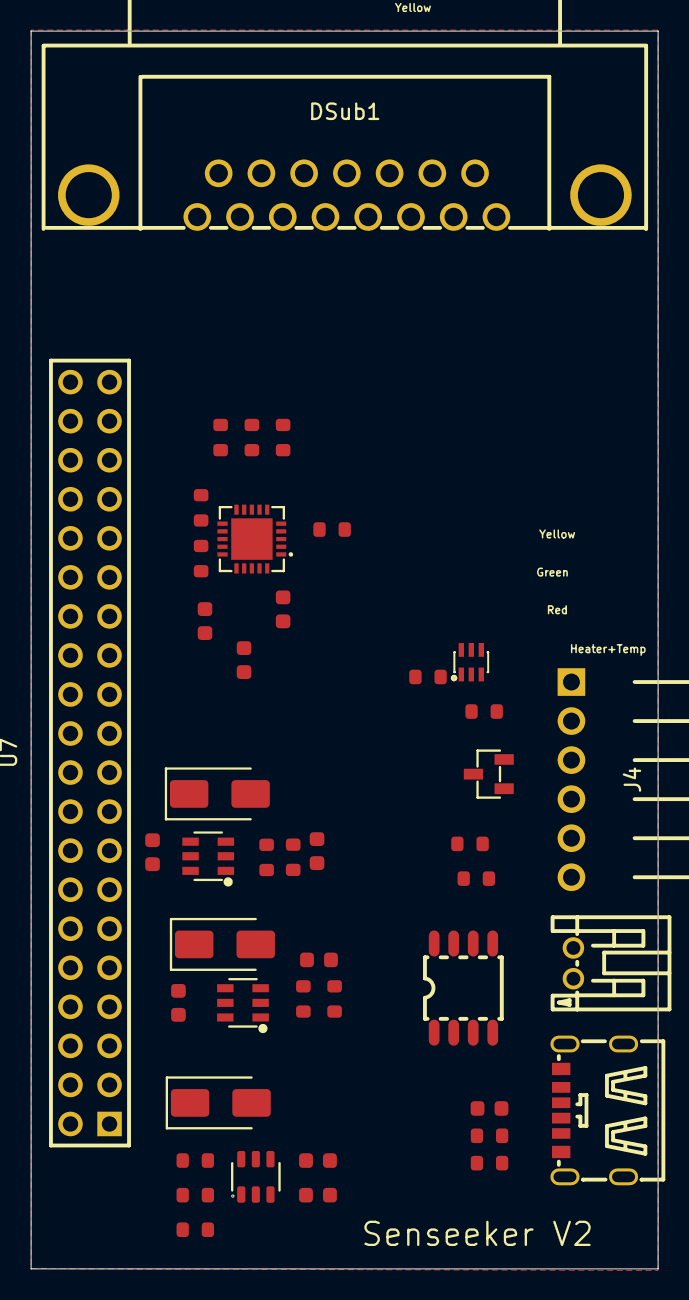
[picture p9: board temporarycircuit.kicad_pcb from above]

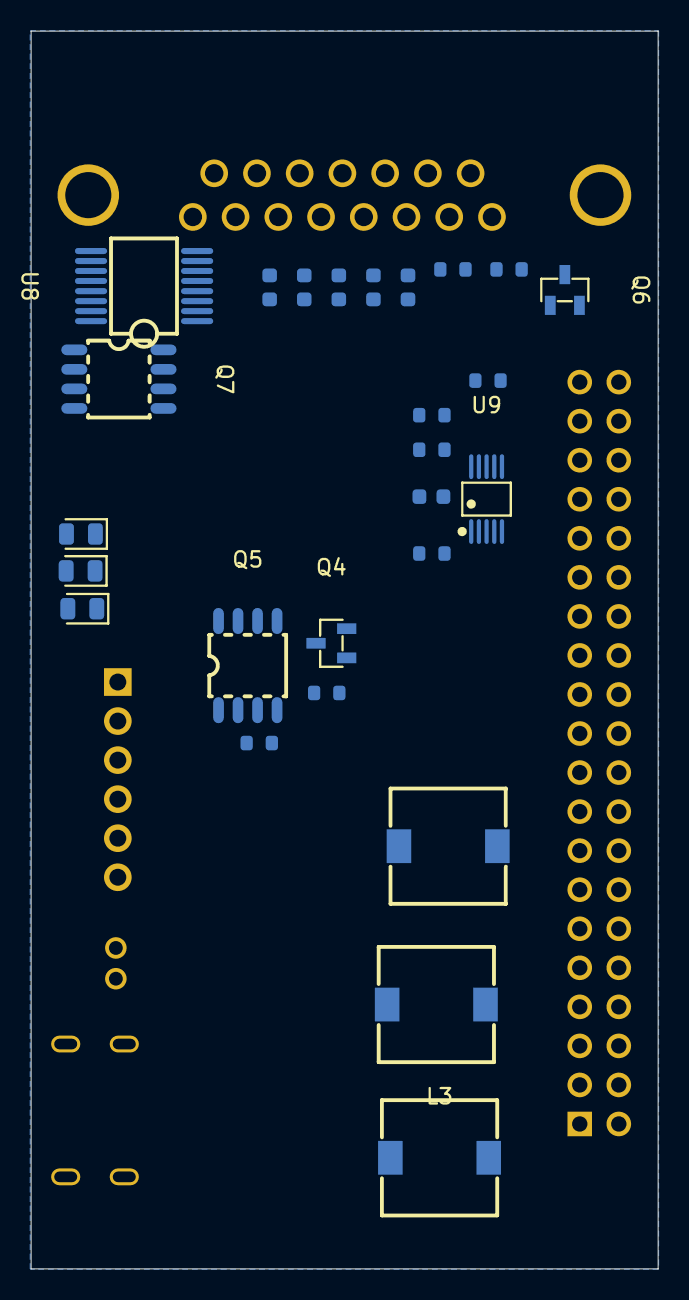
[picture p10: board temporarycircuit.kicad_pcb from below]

Board: 2 copper layers, 40.8 x 80.5 mm, 70 parts (26 on the bottom side), 53 nets, no tracks yet.

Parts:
C1, C6: 4.7uF; C_0603
C2, C12, C17, C18, C19, C20, C21: 100nF; C_0603
C3, C4, C5, C7, C10, C11: 22uF; C_0603
C8: 10uF; C_0603
D1: Red; D_0805
D2: Yellow; D_0805
D3: Green; D_0805
D4, D5, D6: SS34; D_SMA
DSub1: DS1037-15FNAKT74-0CC; DSUB-TH_DS1037-15FNAKT74-0CC
J1: USB_C_Receptacle_PowerOnly_6P; TYPE-C-SMD_TYPE-C-6P
J4: Heater+TempPins; HDR-TH_6P-P2.54-H-M-W10.0
L1, L2, L3: 22uH; IND-SMD_L7.5-W7.5
Q1, Q4, Q6: 2N7002; SOT-23-3_L2.9-W1.3-P1.90-LS2.4-BR
Q2, Q5, Q7: CJQ4435; SOP-8_L5.0-W4.0-P1.27-LS6.2-BL
Q3: currentmirror; SOT-363-6_L2.2-W1.3-P0.65-LS2.1-BL
R1, R2, R12, R13, R21: 5.1kΩ; R_0603
R3: 3kΩ; R_0603
R4: 20kΩ; R_0603
R5, R14, R15, R16: 10kΩ; R_0603
R6, R7, R11: 470Ω; R_0603
R8: 91kΩ; R_0603
R9: 4.7kΩ; R_0603
R10: 22kΩ; R_0603
R18: 6.8kΩ; R_0603
R19: 2kΩ; R_0603
R20: 2.2kΩ; R_0603
R22: 100Ω; R_0603
R23: 240kΩ; R_0603
RPROG1, RPROG4, RPROG5, RPROG6: 1kΩ; R_0603
RPROG3: 10kΩ; R_0603
U2, U3, U6: MT3608; SOT-23-6_L2.9-W1.6-P0.95-LS2.8-BL
U4: MCP73871; QFN-20_L4.0-W4.0-P0.5-BL-EP
U5: Battery Input; CONN-TH_S2B-PH-K-S-GW
U7: 2.54-2*20; HDR-TH_40P-P2.54-V-F-R2-C20-S2.54
U8: MAX3232CDBR; SSOP-16_L6.2-W5.3-P0.65-LS7.8-BL
U9: ADS1115IDGSR; MSOP-10_L3.0-W3.0-P0.50-LS5.0-BL

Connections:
/3.3V: C11.2, C21.1, D6.1, Q5.1 (S), Q5.2 (S), Q5.3 (S), R16.2, R18.1, U8.16 (VCC)
/5 Vout: C4.2, D5.1, R10.1, U7.2, U7.4
/12V: C3.2, D4.1, Q2.1 (S), Q2.2 (S), Q2.3 (S), Q7.1 (S), Q7.2 (S), Q7.3 (S), R8.1, R14.2, R15.2
/A0: J4.5, U9.4 (AIN0)
/A1: J4.6, U9.5 (AIN1)
/Address: R22.2, U9.1 (ADDR)
/GPIO3/SCL1: R12.2, R21.2, U7.5, U9.9 (SDA), U9.10 (SCL)
/GPIO14/TXD0: U7.8, U8.11 (DIN1)
/GPIO15/RXD0: U7.10, U8.12 (ROUT1)
/GPIO18/PCM.CLK: Q1.1 (G), U7.12
/GPIO23: Q6.1 (G), U7.16
/GPIO24: Q4.1 (G), U7.18
/Temp3.3V: C12.1, J4.4, Q5.5 (D), Q5.6 (D), Q5.7 (D), Q5.8 (D), R4.1, R12.1, R13.1, R21.1, RPROG4.1, U9.8 (VDD)
/UART_RX_13V: DSub1.1, U8.13 (RIN1)
/UART_TX_13V: DSub1.2, U8.14 (DOUT1)
/VSYS: C5.1, C6.2, C7.1, C10.1, L1.1, L2.1, L3.1, U2.4 (EN), U2.5 (IN), U3.4 (EN), U3.5 (IN), U4.1 (OUT), U4.20 (OUT), U6.4 (EN), U6.5 (IN)
/base: Q3.2 (B), Q3.5 (B), Q3.6 (C), R23.2
/raspi3.3V: U7.1, U7.17
GND: C1.1, C2.2, C3.1, C4.1, C5.2, C6.1, C7.2, C8.1, C10.2, C11.1, C12.2, C17.2, C18.2, C21.2, DSub1.4, J1.A12 (GND), J1.B12 (GND), J1.S1 (SHIELD), J4.1, Q1.2 (S), Q3.1 (E), Q3.4 (E), Q4.2 (S), Q6.2 (S), R1.2, R2.2, R3.2, R5.2, R9.2, R19.2, R22.1, RPROG1.1, RPROG3.2, RPROG4.2, RPROG5.2, RPROG6.2, U2.2 (GND), U3.2 (GND), U4.10 (V_{SS}), U4.11 (V_{SS}), U4.21 (V_{SS}), U5.2, U6.2 (GND), U7.6, U7.9, U7.14, U7.20, U7.25, U7.30, U7.34, U7.39, U8.15 (GND), U9.3 (GND)
unnamed: D1.1, R7.1
unnamed: D2.1, R11.1
unnamed: D3.1, R6.1
unnamed: DSub1.3, Q7.5 (D), Q7.6 (D), Q7.7 (D), Q7.8 (D), RPROG6.1
unnamed: J1.A5 (CC1), R1.1
unnamed: J1.B5 (CC2), R2.1
unnamed: J4.2, Q2.5 (D), Q2.6 (D), Q2.7 (D), Q2.8 (D), RPROG5.1
unnamed: J4.3, Q3.3 (C)
unnamed: Q1.3 (D), Q2.4 (G), R14.1
unnamed: Q4.3 (D), Q5.4 (G), R16.1
unnamed: Q6.3 (D), Q7.4 (G), R15.1
unnamed: R18.2, R20.1
unnamed: R4.2, R23.1
unnamed: R3.1, R10.2, U2.3 (FB)
unnamed: D5.2, L1.2, U2.1 (SW)
unnamed: R8.2, R9.1, U3.3 (FB)
unnamed: D4.2, L2.2, U3.1 (SW)
unnamed: RPROG1.2, U4.13 (PROG1)
unnamed: RPROG3.1, U4.12 (PROG3)
unnamed: R7.2, U4.8 (STAT1/~LBO)
unnamed: R6.2, U4.7 (STAT2)
unnamed: R5.1, U4.5 (THERM)
unnamed: C1.2, U4.14 (V_{BAT}), U4.15 (V_{BAT}), U4.16 (V_{BAT_SENSE}), U5.1
unnamed: R11.2, U4.6 (~PG)
unnamed: R19.1, R20.2, U6.3 (FB)
unnamed: D6.2, L3.2, U6.1 (SW)
unnamed: C20.1, U8.1 (C1+)
unnamed: C20.2, U8.3 (C1-)
unnamed: C19.1, U8.4 (C2+)
unnamed: C19.2, U8.5 (C2-)
unnamed: C18.1, U8.2 (V+)
unnamed: C17.1, U8.6 (V-)
unnamed: R13.2, U9.2 (ALERT/RDY)
VBUS: C2.1, C8.2, D1.2, D2.2, D3.2, J1.A9 (VBUS), J1.B9 (VBUS), U4.2 (VPCC), U4.3 (SEL), U4.4 (PROG2), U4.9 (~TE), U4.17 (CE), U4.18 (IN), U4.19 (IN)

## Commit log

2026-01-29 Initial commit: KiCad schematic projects
    [BOM-charging-circuit.csv, SchematicProjects.kicad_pcb, SchematicProjects.kicad_sch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]
2026-01-29 Add RS232-converter project with centralized lib references
    [RS232-converter.kicad_pcb, RS232-converter.kicad_sch]
2026-01-29 Add .gitignore for KiCad lock and temp files
2026-02-01 DB15 breakout board design added
    [DB15-breakout.kicad_pcb, DB15-breakout.kicad_sch]
2026-02-16 Initial Traces Complete
    [charging-circuit.kicad_pcb]
2026-02-17 Fixed DRC Thermal Errors
    [BOM-charging-circuit.csv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]
2026-02-17 Final Edits to v2 before sending to Lucas
    [charging-circuit.kicad_pcb]
2026-02-17 bom & cpl . csv
    [bom.csv, designators.csv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]
2026-02-21 Brning in pcb from front of DSUB
    [charging-circuit.kicad_pcb]
2026-02-22 fixed dsub
    [charging-circuit.kicad_pcb, charging-circuit.kicad_sch]
2026-02-22 Edit 3d Model Path
    [charging-circuit.kicad_pcb]
2026-03-03 3s battery
    [3S-Battery.kicad_pcb, 3S-Battery.kicad_sch, BQ24650RVAR.step]
2026-03-06 Add new components and update existing ones in easyeda2kicad library
    - Added BAT-SMD_BH-18650-B5BA016 module for battery SMD.
    - Added HDR-TH_2P-P2.54-V-M-3 and HDR-TH_4P-P2.54-V-M-1 modules for through-hole headers.
    - Introduced R0612, R2512, and R2728 modules for resistors.
    - Updated R0805 module to reference the correct 3D model file.
    - Added RES-SMD_4P-L3.2-W1.6_CSSK0612 and RES-SMD_L6.4-W3.2-R2512 modules for SMD resistors.
    - Added SO-8_L4.9-W3.9-P1.27-LS5.9-BL module for SOIC package.
    - Added SW-SMD_L3.9-W3.0-P4.45 module for SMD switch.
    [3S-Battery.kicad_pcb, 3S-Battery.kicad_sch]
2026-03-10 kicad_sym and Pretty
2026-03-10 Add BQ24170RGYR symbol and VQFN-24 footprint to EasyEDA-KiCad library
    - Introduced the BQ24170RGYR symbol with properties including reference, value, footprint, datasheet, and LCSC part number.
    - Added the VQFN-24 footprint with detailed pad and silk screen definitions for the BQ24170RGYR component.
    [3S-Battery.kicad_sch]
2026-03-11 added devpcb
    [BOM-charging-circuit.csv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]
2026-03-12 3s batterry additions
    [3S-Battery.kicad_sch]
2026-03-12 restructured + lunarvitals circircuit added
    [BOM-charging-circuit.csv, DB15-breakout.kicad_pcb, DB15-breakout.kicad_sch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]
2026-03-12 changed PD circuit
    [charging-circuit.kicad_sch]
2026-03-12 3S Archived
    [3S-Battery.kicad_pcb, 3S-Battery.kicad_sch, BQ24650RVAR.step]
2026-03-12 BQ25895 circuit ref added as Onion_Feather
2026-03-12 renamed ?
    [SchematicProjects.kicad_pcb, SchematicProjects.kicad_sch]
2026-03-12 final schematic
    [charging-circuit.kicad_pcb, charging-circuit.kicad_sch]
2026-03-13 10 of 17 modules completed
    [charging-circuit.kicad_pcb, charging-circuit.kicad_sch]
2026-03-13 Finished Traces and Aligned Modules, Just need to do Mousebites
    [charging-circuit.kicad_pcb]
2026-03-13 KM - Ready For Mousebites, forgot to save on prev commit
    [charging-circuit.kicad_pcb, charging-circuit.kicad_sch]
2026-03-15 Updated Library Paths
    [charging-circuit.kicad_pcb]
2026-03-15 connected VBUS1 on Charge1
    [charging-circuit.kicad_sch]
2026-03-15 added reverse bias diode
    [charging-circuit.kicad_sch]
2026-03-15 Update charging schematic after C913245 import
    [charging-circuit.kicad_sch]
2026-03-17 fixed board layout
    [bom.csv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]
2026-03-17 Mouse Holes replaced with Break Tabs
    [charging-circuit.kicad_pcb]
2026-03-17 fixed drc
    [bom.csv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]
2026-04-15 Modularize charging-circuit schematic
    Split the original flat KiCad schematic into hierarchical sheet files with a top-level overview.
    Preserve PCB connectivity by restoring original component references and validating that the modular netlist matches the flat backup.
    Include the modularization guide, sheet interfaces, and safety backups for the migrated design.
    [01_usbc_pd.kicad_sch, 02_charge1.kicad_sch, 03_usb_bat.kicad_sch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]
2026-04-15 Added LM2596 module to sheet
    [18_lm2596_adj_buck.kicad_sch, charging-circuit.kicad_sch]
2026-04-17 fixed ? in LM2596
    [18_lm2596_adj_buck.kicad_sch]
2026-04-21 added 5V buck
    [01_usbc_pd.kicad_sch, 02_charge1.kicad_sch, 03_usb_bat.kicad_sch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]
2026-04-22 Add TO-263-5 package footprint to easyeda2kicad library
    - Created new footprint for TO-263-5_L10.2-W8.9-P1.70-TL
    - Defined pads, silkscreen, and courtyard outlines
    - Included 3D model reference for visualization
    - Added LCSC part property for component identification
2026-04-22 Fixed issue with footprint not showing up and took off potentiometer
    [18_lm2596_5V_buck.kicad_sch, 18_lm2596_adj_buck.kicad_sch]
2026-04-22 changed to 5v
    [18_lm2596_5V_buck.kicad_sch]
2026-04-22 added pin 6 to gnd
    [18_lm2596_5V_buck.kicad_sch]
2026-04-22 created VSENS V3
    [01_usbc_pd.kicad_sch, 02_charge1.kicad_sch, 03_usb_bat.kicad_sch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]
2026-04-23 Refactor code structure for improved readability and maintainability
    [01_usbc_pd.kicad_sch, 04_sleepmosfet.kicad_sch, 07_ic2_breakout.kicad_sch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]
2026-04-29 added a final PCB folder
    [01_usbc_pd.kicad_sch, 02_charge1.kicad_sch, 03_usb_bat.kicad_sch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]
2026-04-29 more intilaization
    [final.kicad_pcb]
2026-04-30 Fixed formatting issues, now the hierachal sheets are all labeled as net labels and when we want to expose their pins we will make them into hierchal or global pins
    [01_usbc_pd.kicad_sch, 02_charge1.kicad_sch, 03_usb_bat.kicad_sch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]
2026-04-30 deleted and refromatted files
    [01_usbc_pd.kicad_sch, 02_charge1.kicad_sch, 03_usb_bat.kicad_sch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]
2026-04-30 deleted final
    [BOM-charging-circuit.csv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]
2026-04-30 formatting changes for LM2596, now ready to branch of off and make our seperate PCB and then compare
    [04_sleepmosfet.kicad_sch, 05_fuelgauge.kicad_sch, 14_3s_ic.kicad_sch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]
2026-04-30 updating to kicad 10.0
    [04_sleepmosfet.kicad_sch, 05_fuelgauge.kicad_sch, 14_3s_ic.kicad_sch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]
